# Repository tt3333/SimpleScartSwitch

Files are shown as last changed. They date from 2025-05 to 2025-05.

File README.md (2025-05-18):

[日本語版 README はこちら](README-ja.md)

# Simple SCART Switch

This is a switcher that can switch between two SCART inputs.

Cheap SCART switchers sold at AliExpress for less than 1000 Japanese yen only support composite and not RGB.<br>
Most SCART switchers that support RGB have more input terminals than necessary, so they take up a lot of space and are expensive.<br>
Therefore, I designed a simple 2-input switcher that supports RGB.

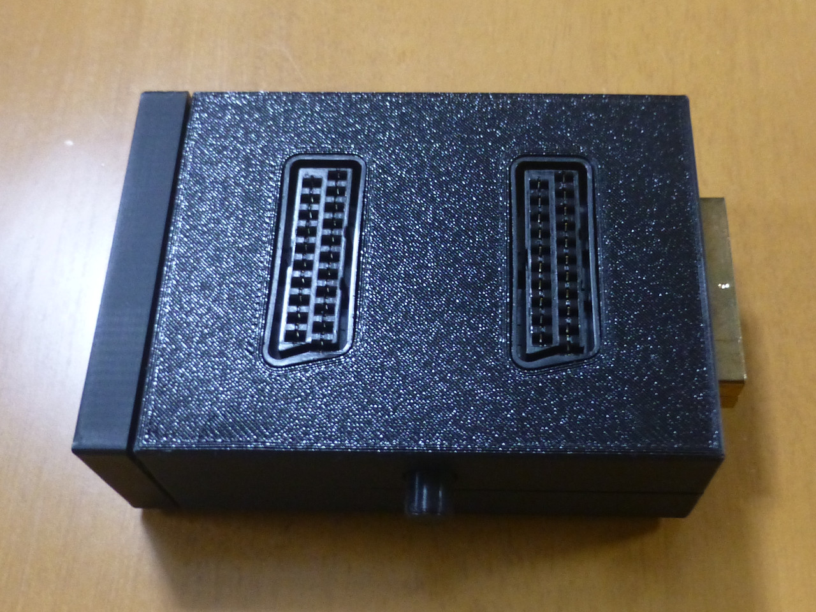
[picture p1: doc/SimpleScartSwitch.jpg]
SimpleScartSwitch


## How to Build

### Required Parts

- SCART plug 2 pcs
    - https://ja.aliexpress.com/item/1005006514947794.html
- SCART socket 2 pcs
    - https://ja.aliexpress.com/item/1005007196215986.html
- switch (8PDT, 1 Row) 1 pc
    - https://ja.aliexpress.com/item/4000353452952.html
    - https://www.amazon.co.jp/dp/B0D8HYP276
- pan head screw (M3, 6-15mm) 2 pcs
- pan head screw (M3, 8-15mm) 4 pcs
- cushion rubber 4 pcs

### Ordering PCBs

Upload gerber.zip to a board manufacturer's website and order the board.<br>
For JLCPCB, it is recommended to select "Yes" from the "Remove Order Number" options.

### Printing Cases

Print top.stl, bottom.stl and plug_cap.stl with a 3D printer.<br>
If the switch does not come with a cap, please also print switch_cap.stl.

### Assembly

1. Place pieces of paper between the pins of the SCART plugs and the board,<br>
   and temporarily fix the SCART plugs with cellophane tape or similar.
2. Solder the pins on both ends of the SCART plugs.
3. Remove the tape and paper and solder the remaining pins of the SCART plugs.
4. Solder the switch.
5. Solder the SCART sockets.
6. Fasten the board to the case with two screws.
7. Close the case with four screws.
8. Attach cushion rubber to the four corners of the bottom.

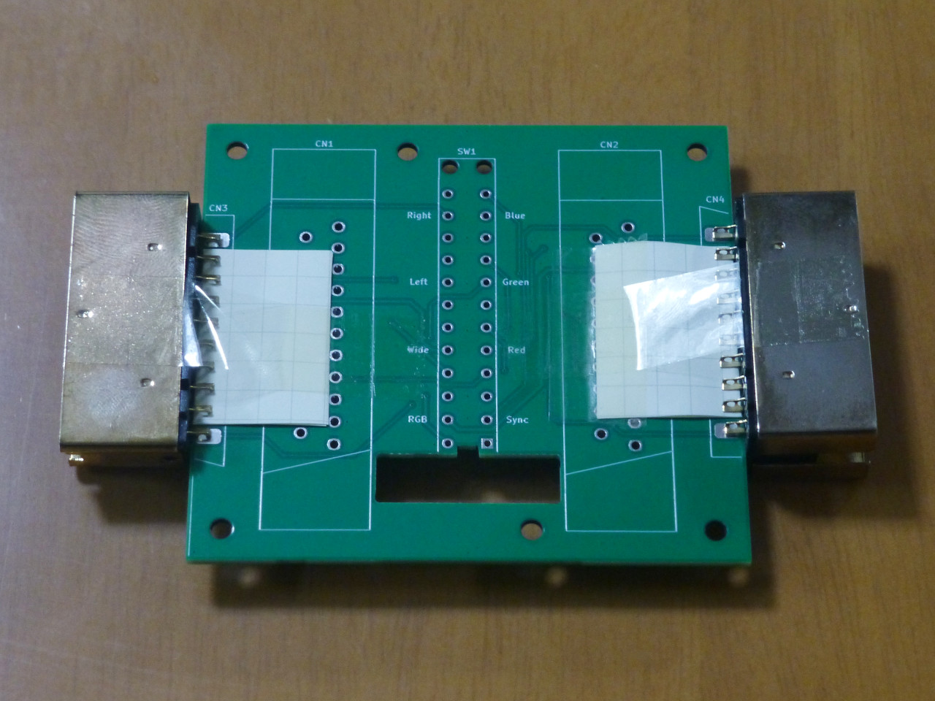
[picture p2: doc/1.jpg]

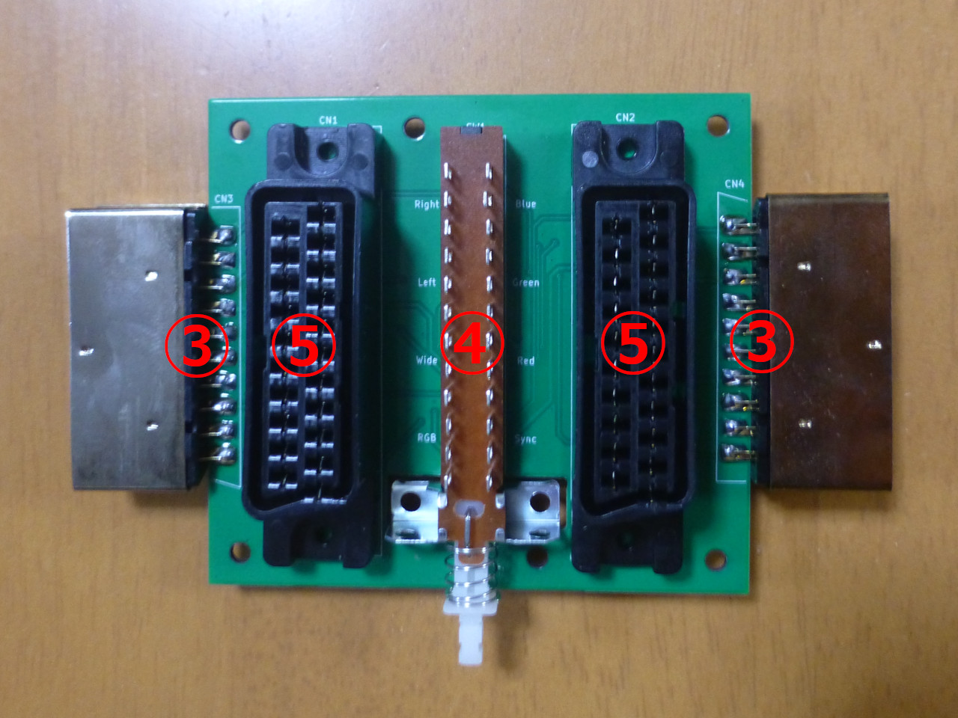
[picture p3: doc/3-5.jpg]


## How to Use

- Connect either the left or right plug to the output destination device.<br>
  (Do not use both left and right plugs at the same time.)<br>
  You can align the wiring direction by using the right side plug when connecting to the RetroTINK-5X Pro or the left side plug when connecting to the RetroTINK-4K Pro.
- Put the cap on the plug of the one not in use.
- Connect input sources such as game consoles to the sockets on the top.
- You can switch inputs with the switch on the front.

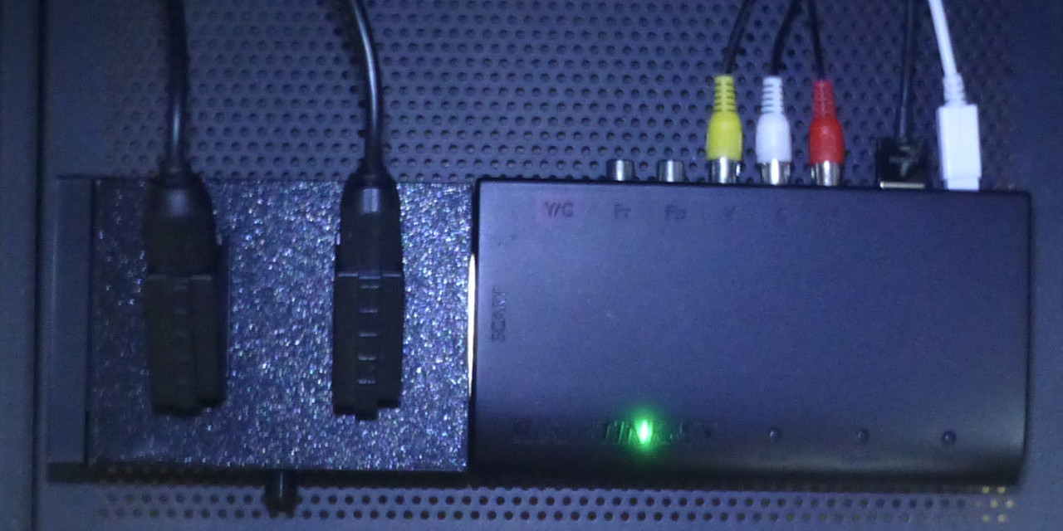
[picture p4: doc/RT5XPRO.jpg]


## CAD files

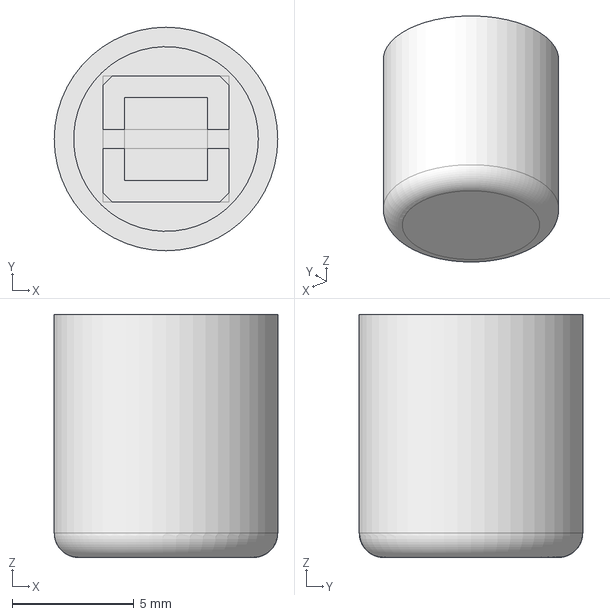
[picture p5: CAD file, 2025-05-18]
FreeCAD/switch_cap.FCStd
9.20 x 9.20 x 10.0 mm

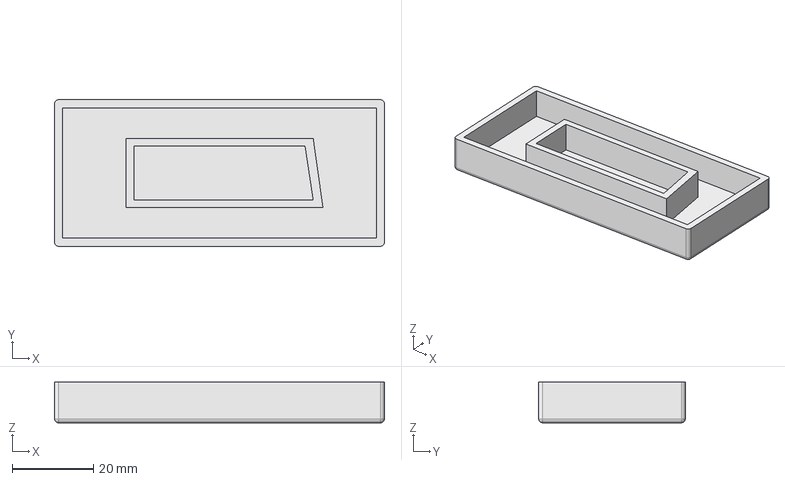
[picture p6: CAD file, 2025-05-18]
FreeCAD/plug_cap.FCStd
81.0 x 36.0 x 10.0 mm

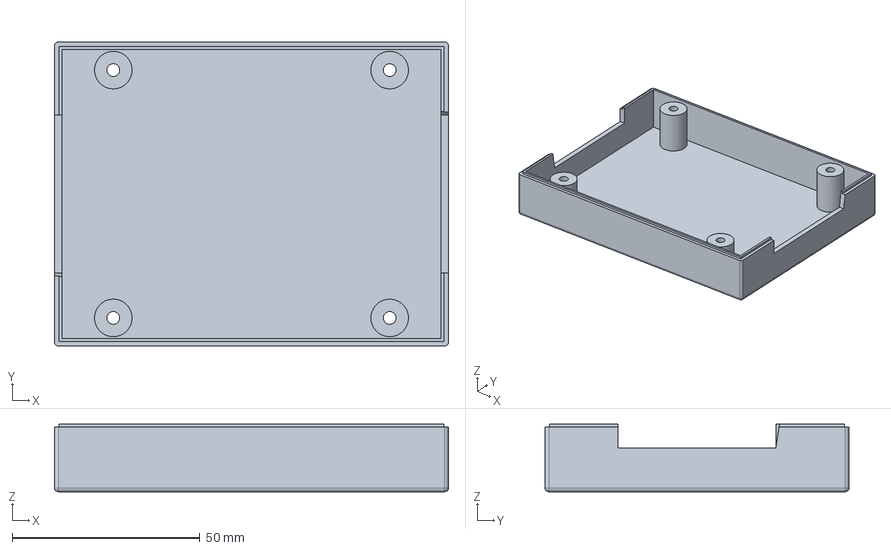
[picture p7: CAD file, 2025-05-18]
FreeCAD/bottom.FCStd
105.0 x 81.0 x 18.0 mm
ボディ|体

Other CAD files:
FreeCAD/bottom.stl
FreeCAD/plug_cap.stl
FreeCAD/switch_cap.stl

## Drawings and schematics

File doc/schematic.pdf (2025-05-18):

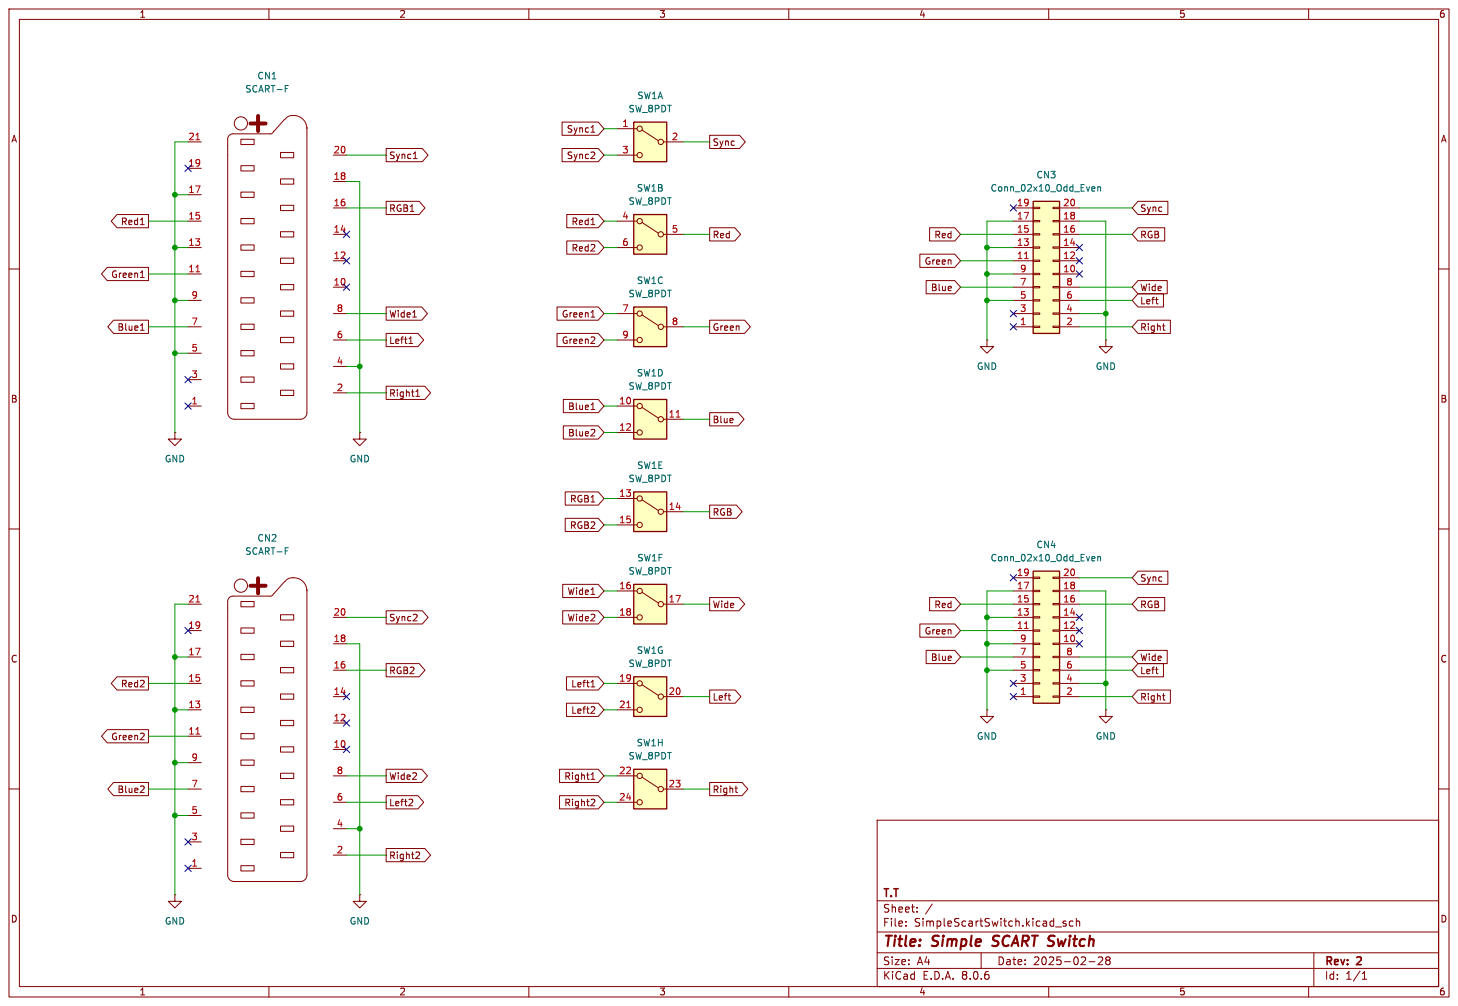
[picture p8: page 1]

Id: 1/1 Title: Simple SCART Switch

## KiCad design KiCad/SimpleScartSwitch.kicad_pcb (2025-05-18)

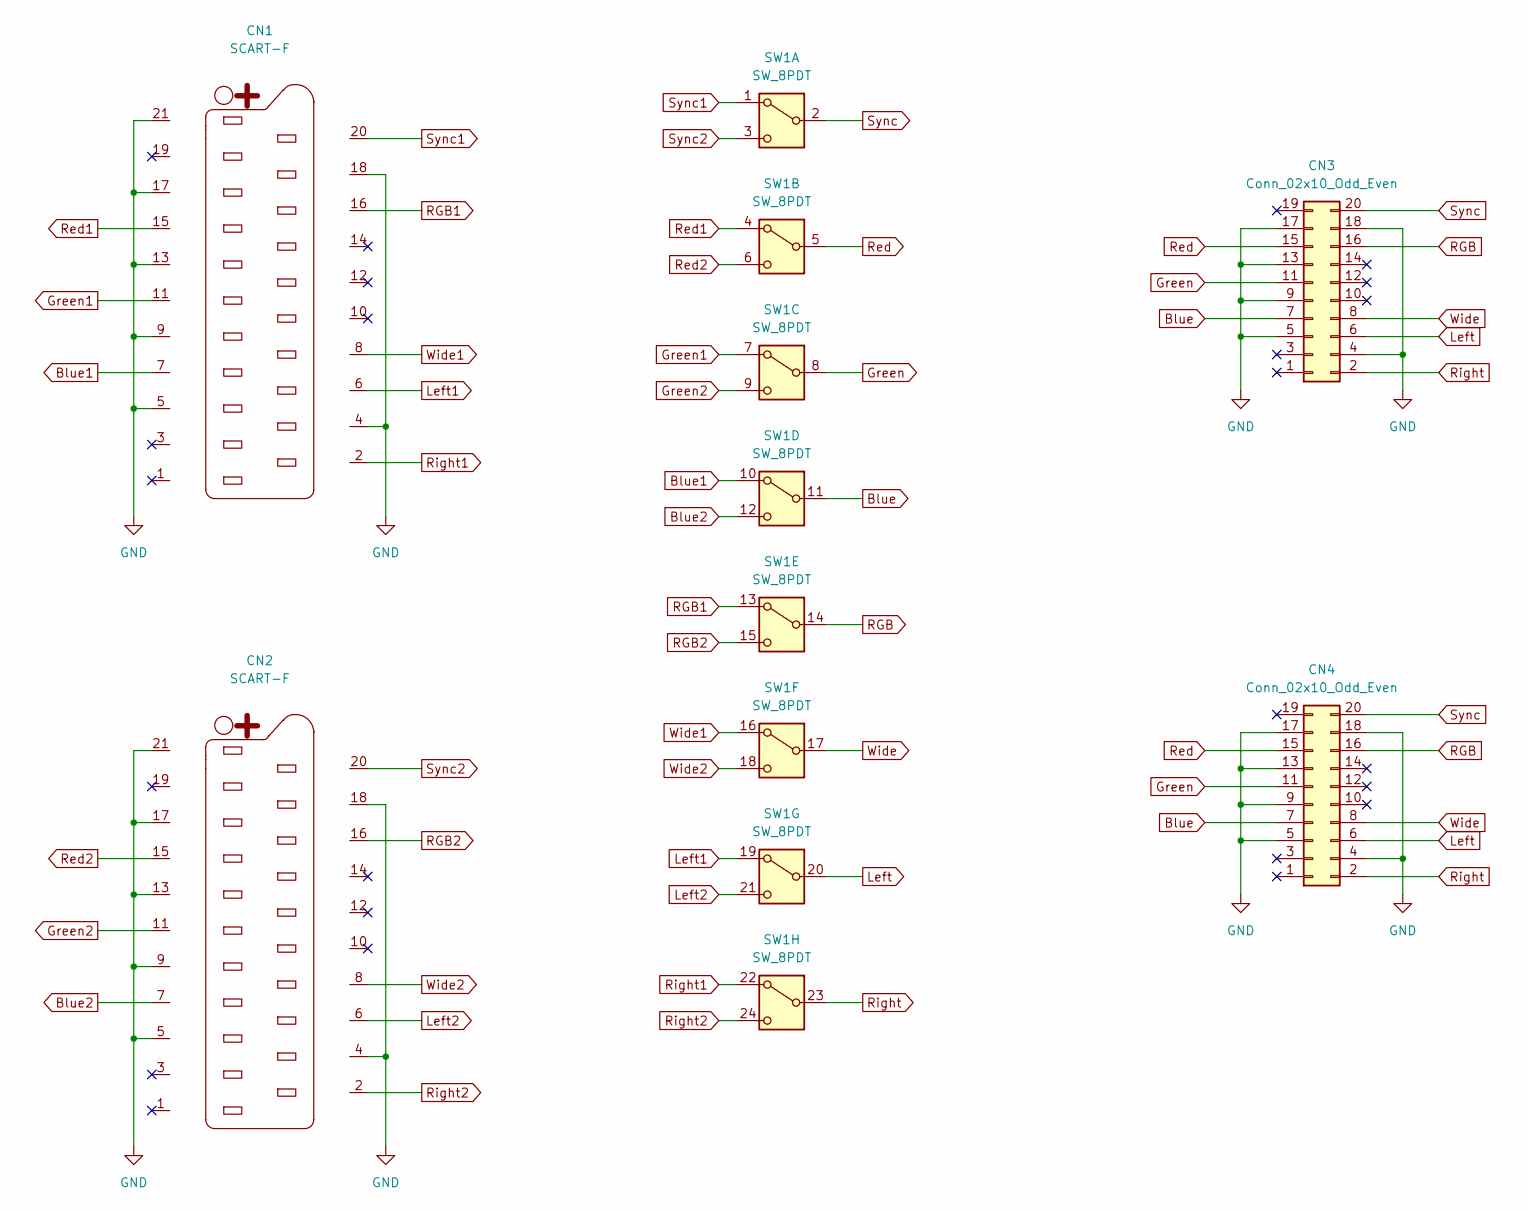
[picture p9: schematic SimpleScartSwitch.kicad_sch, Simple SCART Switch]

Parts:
CN1, CN2: SCART-F; SCART_Socket
CN3, CN4: Conn_02x10_Odd_Even; SCART_Plug
SW1: SW_8PDT; 8PDT

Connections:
Blue: CN3.7, CN4.7, SW1.11 (B)
Blue1: CN1.7, SW1.10 (A)
Blue2: CN2.7, SW1.12 (C)
GND: CN1.4, CN1.5, CN1.9, CN1.13, CN1.17, CN1.18, CN1.21, CN2.4, CN2.5, CN2.9, CN2.13, CN2.17, CN2.18, CN2.21, CN3.4, CN3.5, CN3.9, CN3.13, CN3.17, CN3.18, CN4.4, CN4.5, CN4.9, CN4.13, CN4.17, CN4.18
Green: CN3.11, CN4.11, SW1.8 (B)
Green1: CN1.11, SW1.7 (A)
Green2: CN2.11, SW1.9 (C)
Left: CN3.6, CN4.6, SW1.20 (B)
Left1: CN1.6, SW1.19 (A)
Left2: CN2.6, SW1.21 (C)
RGB: CN3.16, CN4.16, SW1.14 (B)
RGB1: CN1.16, SW1.13 (A)
RGB2: CN2.16, SW1.15 (C)
Red: CN3.15, CN4.15, SW1.5 (B)
Red1: CN1.15, SW1.4 (A)
Red2: CN2.15, SW1.6 (C)
Right: CN3.2, CN4.2, SW1.23 (B)
Right1: CN1.2, SW1.22 (A)
Right2: CN2.2, SW1.24 (C)
Sync: CN3.20, CN4.20, SW1.2 (B)
Sync1: CN1.20, SW1.1 (A)
Sync2: CN2.20, SW1.3 (C)
Wide: CN3.8, CN4.8, SW1.17 (B)
Wide1: CN1.8, SW1.16 (A)
Wide2: CN2.8, SW1.18 (C)

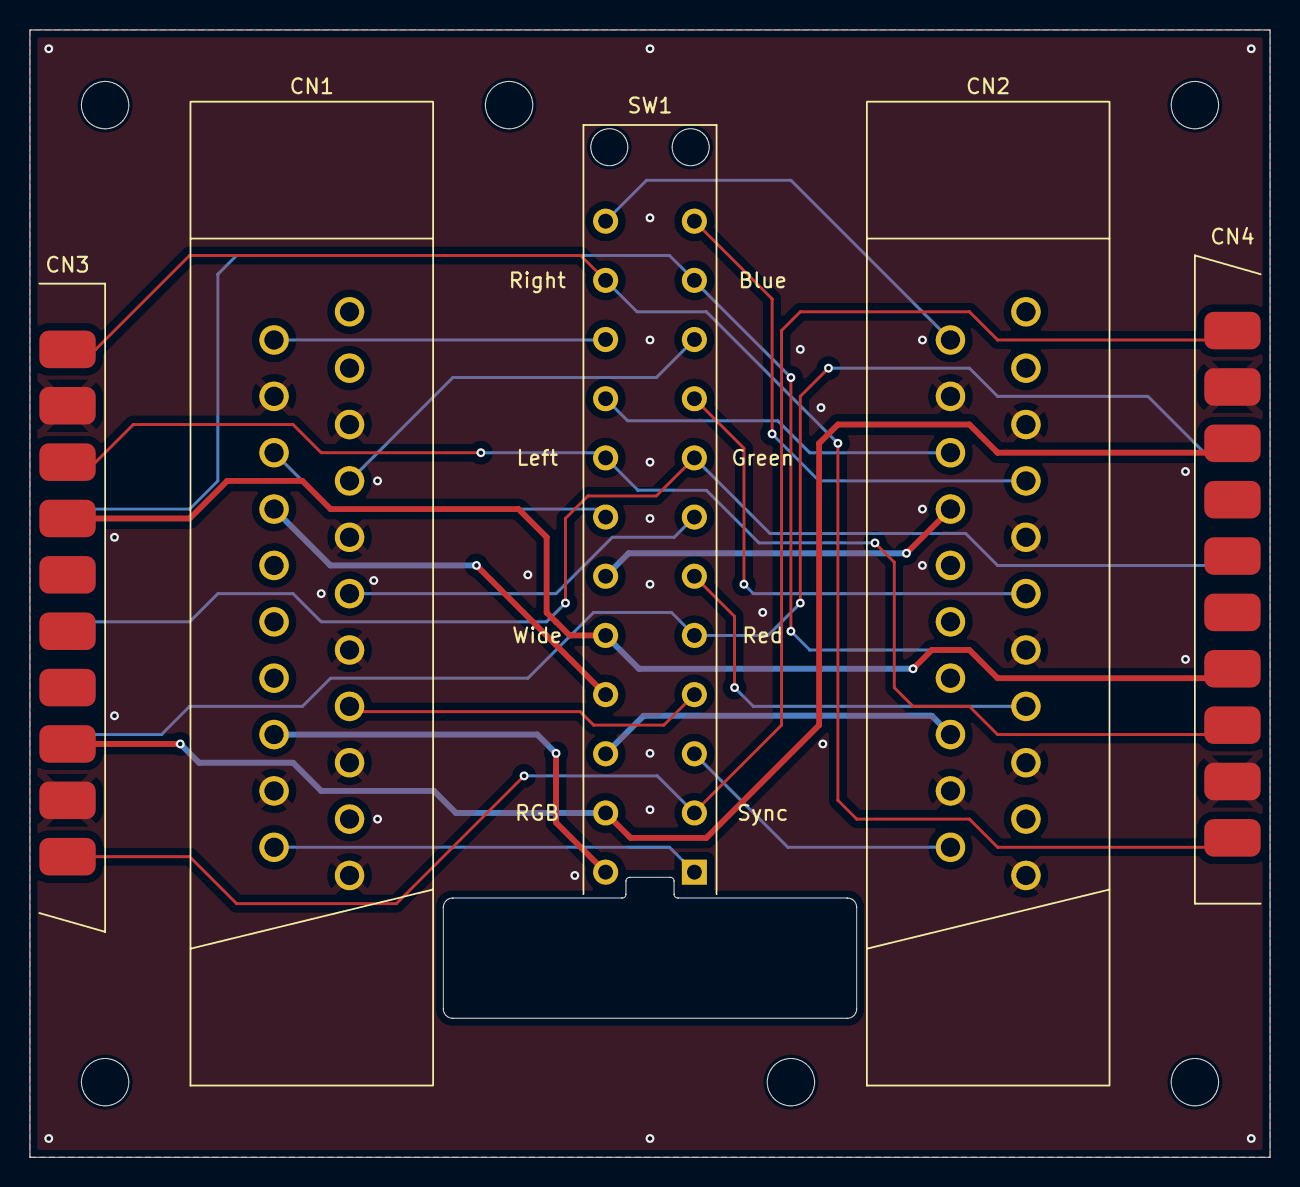
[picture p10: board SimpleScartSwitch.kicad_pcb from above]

Board: 2 copper layers, 83.8 x 76.2 mm, 5 parts (0 on the bottom side), 25 nets.

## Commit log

2025-02-01 add KiCad project
    [SimpleScartSwitch.kicad_pcb, SimpleScartSwitch.kicad_sch]
2025-02-01 add schematic.pdf
2025-02-01 add gerber file
2025-02-01 add PCB image
2025-03-26 add FreeCAD project
    [bottom.FCStd, cap.FCStd]
2025-05-18 SCART plugs can be soldered directly to the board
    [SimpleScartSwitch.kicad_pcb, SimpleScartSwitch.kicad_sch, bottom.FCStd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]

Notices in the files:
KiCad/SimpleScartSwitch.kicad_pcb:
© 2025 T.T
